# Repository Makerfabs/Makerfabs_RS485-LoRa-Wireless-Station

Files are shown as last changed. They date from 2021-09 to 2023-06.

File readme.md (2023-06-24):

# Industrial-grade Soil Remote Monitor

```c++
/*
Version:		V2.0
Author:			Vincent
Create Date:	2023/3/1
Note:
		2023/3/1	V2.0: Use new sensor, change request code.
*/
```

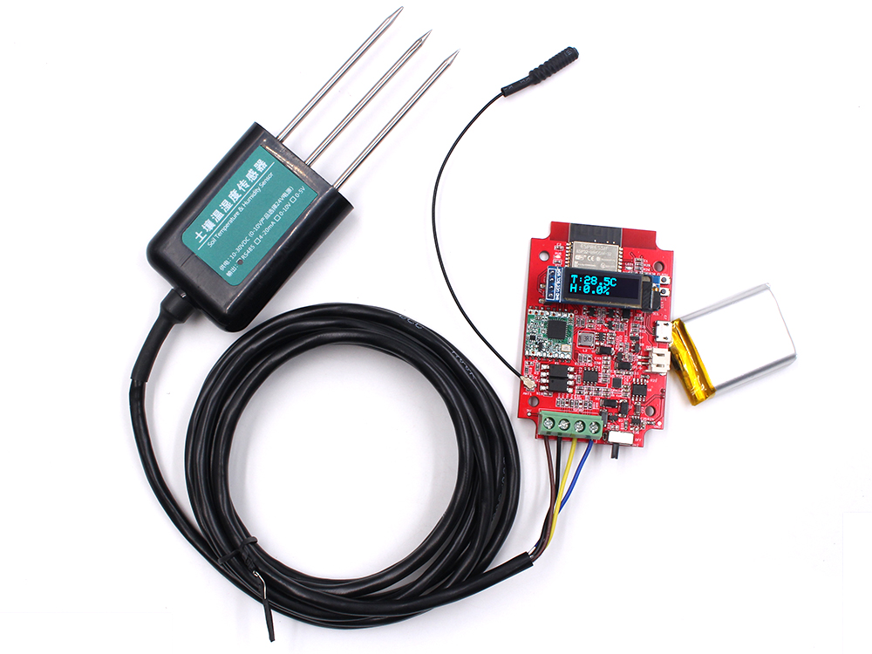
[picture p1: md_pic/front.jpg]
main


[toc]

# Makerfabs

[Makerfabs home page](https://www.makerfabs.com/)

[Makerfabs Wiki](https://wiki.makerfabs.com/)

# Industrial-grade Soil Remote Monitor

## Intruduce

Product Link ：[Industrial-grade Soil Remote Monitor(Humidity/ Temperature/ PH/ Nitrogen/ Phosphorus/ Potassium)](https://www.makerfabs.com/industrial-grade-soil-remote-monitor.html) 

Wiki Link : [RS485-LoRa Wireless Station](https://wiki.makerfabs.com/Industrial-grade_Soil_Remote_Monitor.html) 

With the development of agricultural modernization and the popularization of precision agriculture, the remote monitoring of soil parameters such as temperature, moisture, PH, and so on, becomes more important.

This Industry-grade soil remote monitor intends for these applications of agriculture, it is mainly composed of 2 parts:

**1. Remote monitor station with RS485:** developed by Makerfabs, it converts the RS485 signal, which is usually used in agricultural field applications, to wireless connections WIFI (if there is) or Lora, or Bluetooth.
**2. Industrial-grade Soil Sensor:** unlike some other maker-level soil sensors that only output analog voltage that reflects the soil status/changes but not the absolute value, this sensor measures the soil parameters such Temperature/Moisture/PH/Nitrogen/ Phosphorus/Potassium.., with calculated true output, so users can get to know the real soil parameters.

## Feature

- ESP32 WROOM module onboard with the WiFi and Bluetooth
- Arduino Compatible: You can play it with Arduino IDE
- Onboard LoRa module (433Mhz or 868Mhz or 915Mhz)
- 0.91inch I2C OLED display
- Sensor part is waterproof, completely sealed
- Measuring range: -40℃~80℃，0~100% moisture
- Measuring accuracy: ±0.5℃，±3% moisture
- Communication distance: Lora: 2km or more; WIFI: No such parameter
- Power by Micro USB, battery, or DC 5V
- 1000mAh battery, charger IC onboard

# Code

## Compiler Options

**If you have any questions，such as how to install the development board, how to download the code, how to install the library. Please refer to :[Makerfabs_FAQ](https://github.com/Makerfabs/Makerfabs_FAQ)**

- Install board : ESP32 .
- Install library : Adafruit GFX library (V1.10.11) , Adafruit SSD1306 library (V2.4.6) and RadioLib library 4.0.6.
- Upload codes, select "ESP32 Dev Module"

## Sensor User Manual

Cable definition:

- Grey cable: DC 5V power supply +
- Black line: Power ground (GND)
- Yellow and green wires: RS485-A;
- Brown cable: RS485-B.

The sensor uses Modbus RTU.

Request Command：**01 04 00 00 00 07 B1 C8**

- 0x01 Sensor address; 
- 0x04 function code; 
- 0x00 0x00 read register start position; 
- 0x00 0x07 Number of registers read; 
- 0xB1 0xC8  Check

Receive Data：**01 04 0E 01 D7 01 07 00 00 00 46 00 0F 00 14 00 32 CC 93**

- 0x01 Sensor address;
- 0x04 function code;
- 0x0E data length;
- 0x01 0xD7 Soil moisture data 01 D7 (hexadecimal) is 47.1%
- 0x01 0x07 Soil Temperature Data 01 07 (hexadecimal) is 26.3 ° C
- 0x00 0x00 blank
- 0x00 0x46 PH data 00 46 (hexadecimal) is 7.0
- 0x00 0x0F Soil Nitrogen data 00 0F (hexadecimal) is 15mg/kg
- 0x00 0x14 Soil Phosphorus data 00 14 (hexadecimal) is 20mg/kg
- 0x00 0x32 Soil potassium data 00 32 (hexadecimal) is 50mg/kg
- 0xCC 0x93 check

| Parameter | Address | Range | Sampling Value | Action |
| --- | --- | --- | --- | --- |
| Humidity | 0000H | 0~100% | /10 | Only Read |
| Temperature | 0001H | -40~80℃ | /10 | Only Read |
| PH | 0003H | 4~9 | /10 | Only Read |
| Nitrogen | 0004H | 0~1999mg/kg | /1 | Only Read |
| Phosphorus  | 0005H | 0~1999mg/kg | /1 | Only Read |
| Potassium | 0006H | 0~1999mg/kg | /1 | Only Read |

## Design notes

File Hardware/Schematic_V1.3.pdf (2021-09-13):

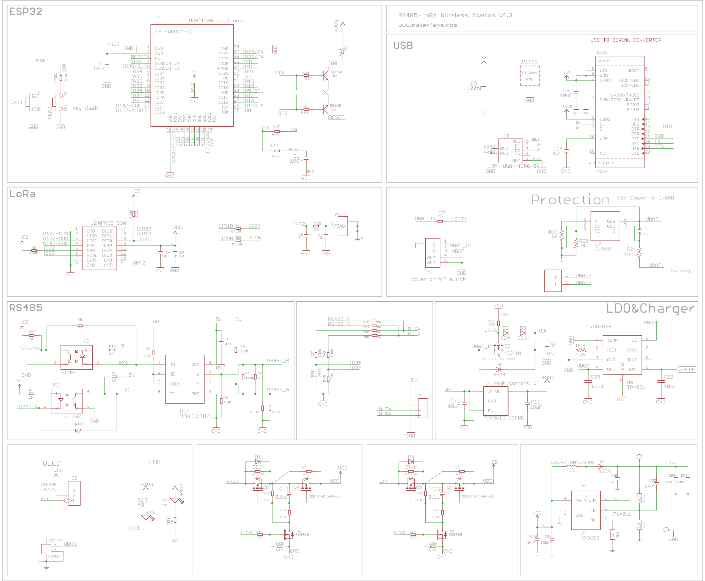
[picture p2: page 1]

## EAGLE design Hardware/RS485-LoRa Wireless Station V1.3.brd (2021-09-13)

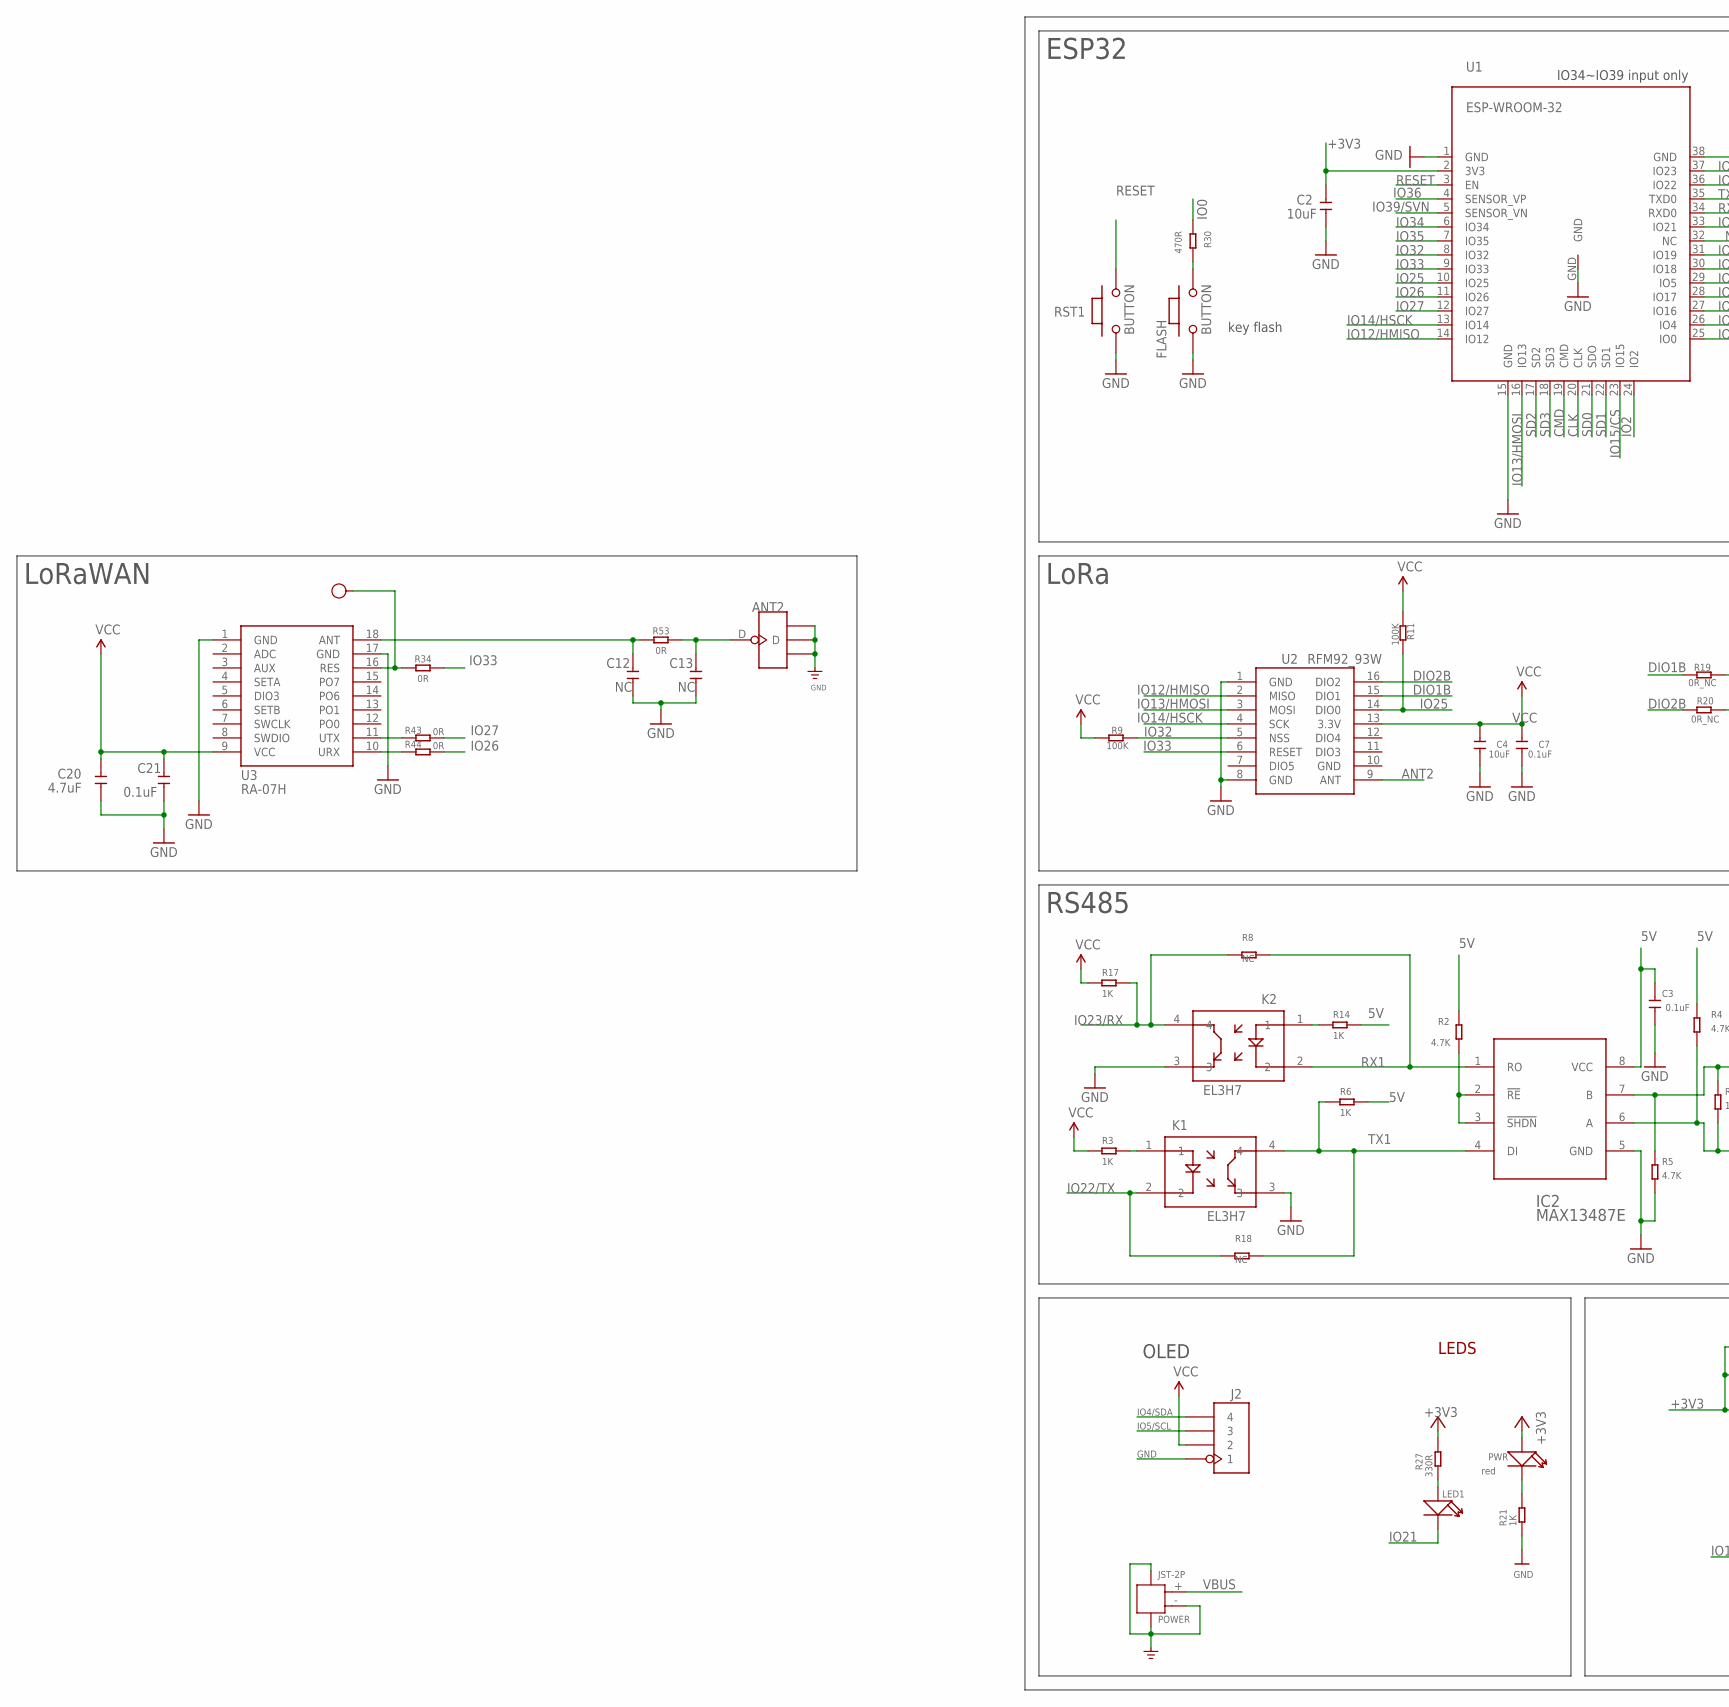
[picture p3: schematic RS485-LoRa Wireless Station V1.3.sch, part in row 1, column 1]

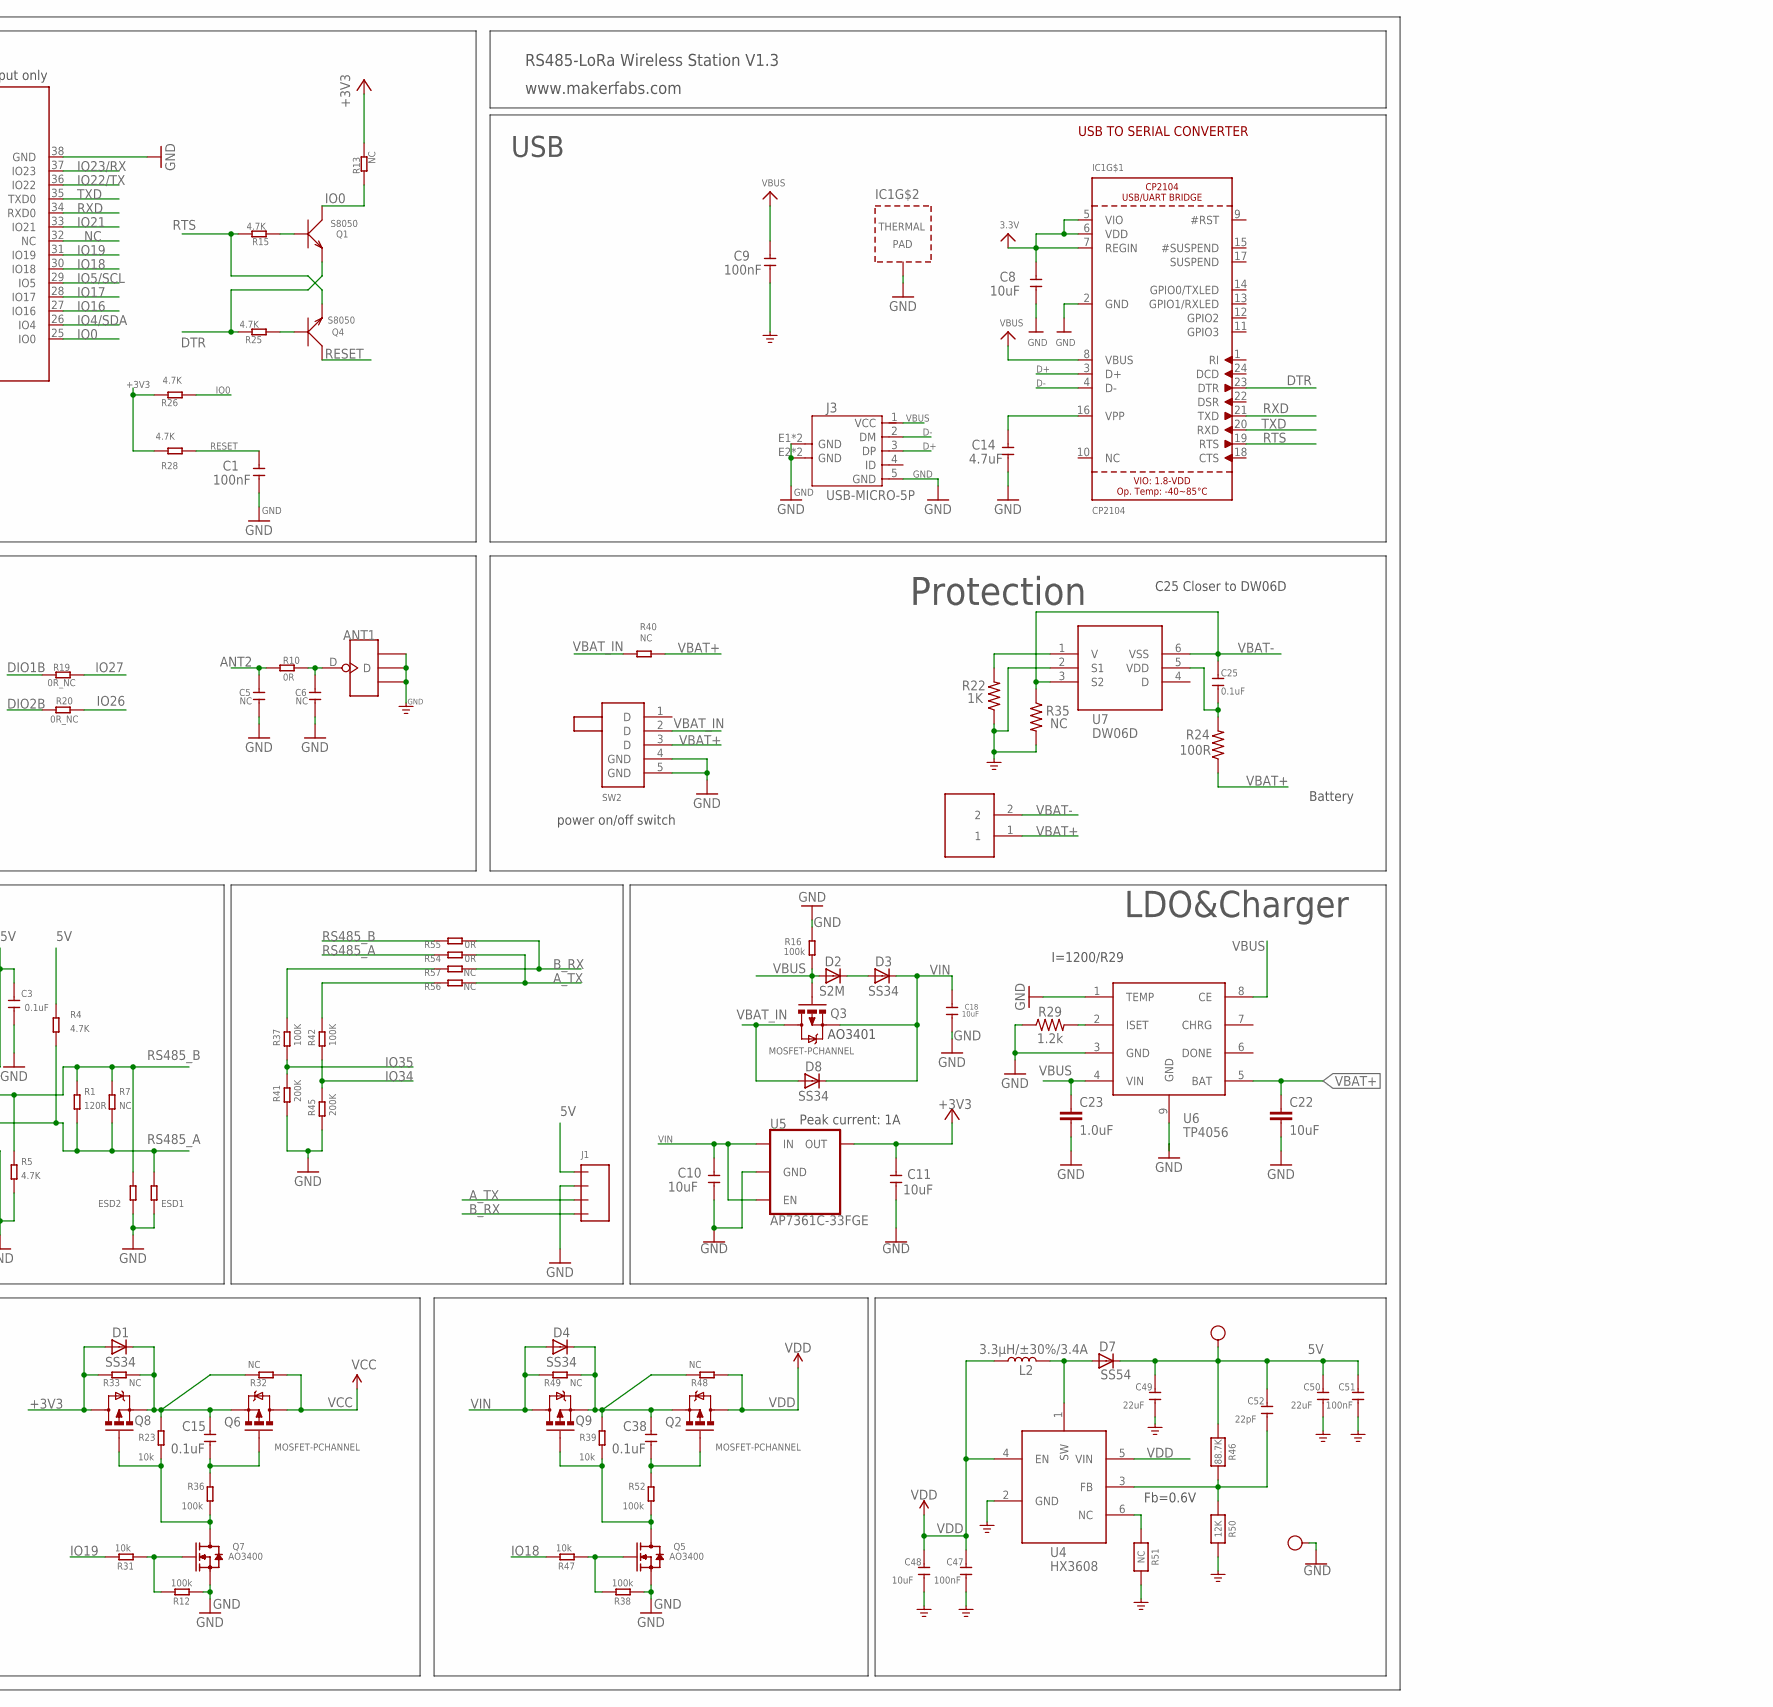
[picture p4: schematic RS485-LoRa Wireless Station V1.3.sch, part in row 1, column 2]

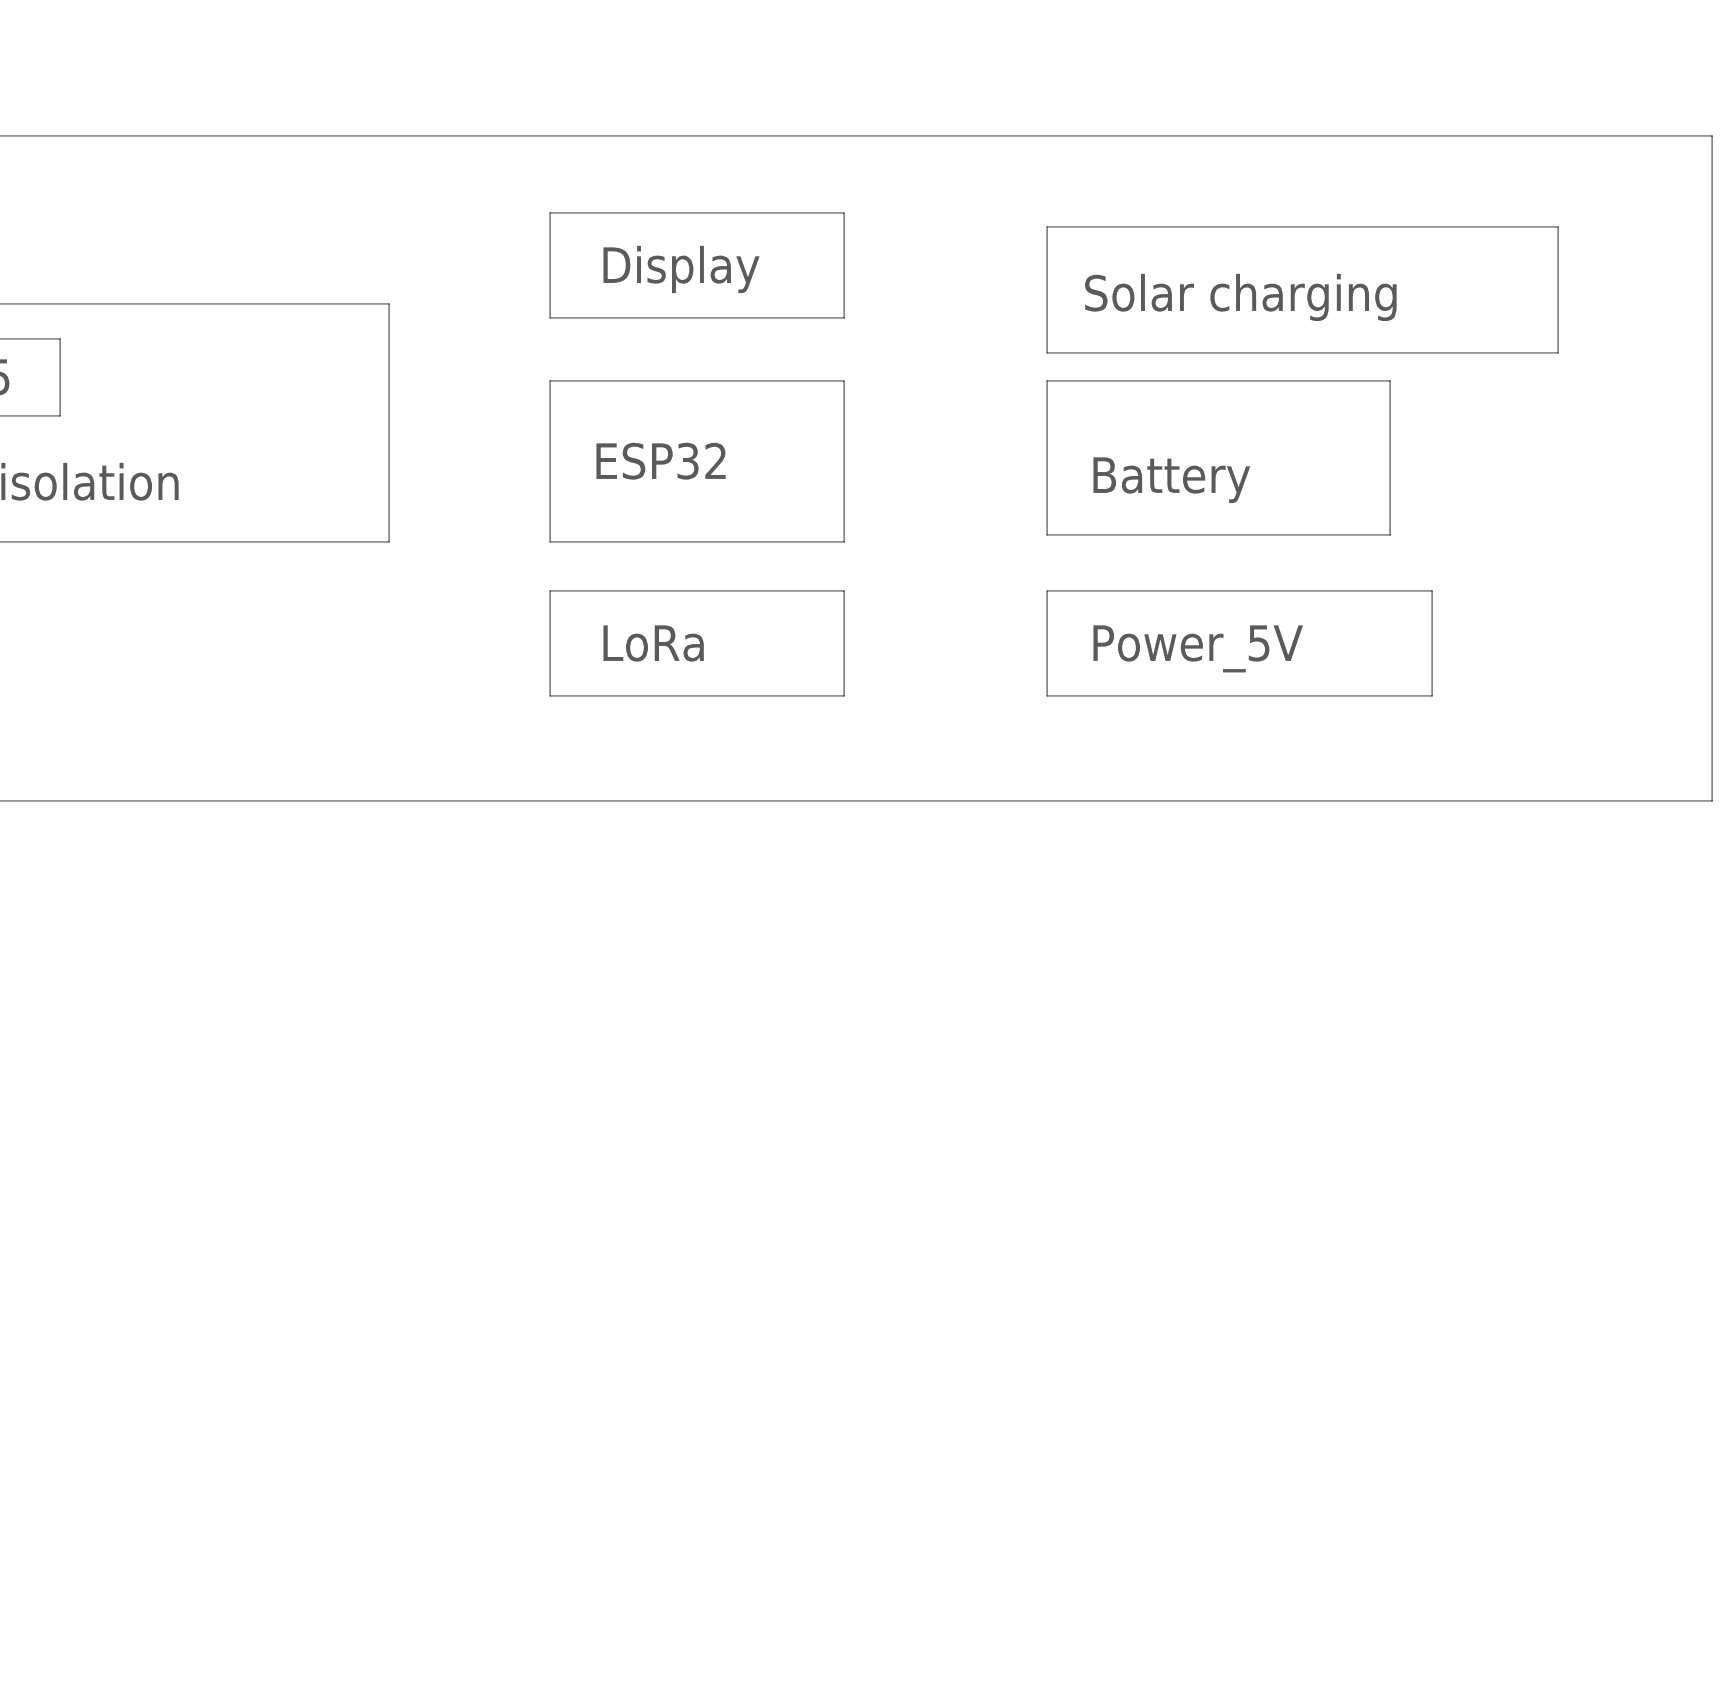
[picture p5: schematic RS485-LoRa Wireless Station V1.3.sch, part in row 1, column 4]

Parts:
5V: TEST-POINT'4545'; TP-D45MIL
ANT1, ANT2: ANTENNA-U-FL; 4P-U-FL
C1, C9, C47, C51: 100nF; C0603
C2, C4, C8, C10, C11, C18, C48: 10uF; C0603
C3, C7, C15, C21, C25, C38: 0.1uF; C0603
C5, C6: NC; DISCRETE_C0603
C12, C13: NC; C0603
C14, C20: 4.7uF; C0603
C22: 10uF; 1206
C23: 1.0uF; 0603
C49, C50: 22uF; C0603
C52: 22pF; C0603
D1, D3, D4, D8: SS34; DO-214AC
D2: S2M; DO-214AC
D7: SS54; DO-214AC
ESD1, ESD2: R-0603; R0603
FLASH: BUTTON; 157SW
GND: TEST-POINT'4545'; TP-D45MIL
IC1: CP2104; QFN24_4MM_SMSC
IC2: MAX13487E; DIP8_MAX13487
J1: J_4P_5.08; DIP4_5.08
J2: HEADER-1X4P; SMD4-2.54P
J3: USB-MICRO-5P; MICRO-USB-5P
J5: PH2.0-2P-90-DIP
K1, K2: EL3H7; SOP-4_P1.27
L2: 3.3µH/±30%/3.4A; CR54
LED1: DISCRETE_LED0603; DISCRETE_LED-0603
POWER: JST-2P; HW2-SMD-2.0-90D
PWR: red; LED-0603
Q1, Q4: S8050; SOT23
Q2, Q3, Q6, Q8, Q9: MOSFET-PCHANNEL; SOT23-3
Q5, Q7: AO3400; SOT23@1
R1: 120R; R0603
R2, R4, R5, R15, R25, R26, R28: 4.7K; R0603
R3, R6, R14, R17, R21: 1K; R0603
R7, R8, R13, R18, R32, R33, R40, R48, R49, R56, R57: NC; R0603
R9, R11, R37, R42: 100K; R0603
R10: 0R; DISCRETE_R0603
R12, R16, R36, R38, R52: 100k; R0603
R19, R20: 0R_NC; R0603
R22: 1K; 0603
R23, R31, R39, R47: 10k; R0603
R24: 100R; 0603
R27: 330R; R0603
R29: 1.2k; 0603
R30: 470R; R0603
R34, R43, R44, R53, R54, R55: 0R; R0603
R35: NC; 0603
R41, R45: 200K; R0603
R46: 88.7K; 0603-NO
R50: 12K; 0603-NO
R51: NC; 0603-NO
RES: TEST-POINT'4545'; TP-D45MIL; PARTNO DNP
RST1: BUTTON; 157SW
SW2: SWITCH; DIP5-8.6*4.5MM
U1: ESP-WROOM-32
U2: RFM92_93W
U3: RA-07H; SMD18-127P-1600L1600W
U4: HX3608; SOT-23-6
U5: AP7361C-33FGE; 8-UDFN
U6: TP4056; SOP8-1.27P
U7: DW06D; SOT-23-6

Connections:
5V: 5V.T, C3.2, C49.1, C50.1, C51.1, C52.1, D7.C, IC2.8 (VCC), J1.P$1 (1), R2.2, R4.2, R6.1, R14.1, R46.1
+3V3: C2.2, C8.2, C11.2, D1.A, IC1.5 (VIO), IC1.6 (VDD), IC1.7 (REGIN), PWR.+, Q8.3 (D), R13.1, R26.1, R27.2, R28.1, R33.2, U1.2 (3V3), U5.1 (OUT)
ANT2: C5.2, R10.1, U2.9 (ANT)
A_TX: J1.P$3 (3), R54.1, R56.1
B_RX: J1.P$4 (4), R55.1, R57.1
CLK: U1.20 (CLK)
CMD: U1.19 (CMD)
D+: IC1.3 (D+), J3.3 (DP)
D-: IC1.4 (D-), J3.2 (DM)
DIO1B: R19.2, U2.15 (DIO1)
DIO2B: R20.2, U2.16 (DIO2)
DTR: IC1.23 (DTR), Q1.2 (E), R25.1
GND: ANT1.GND1, ANT1.GND2, ANT1.GND3, ANT2.GND1, ANT2.GND2, ANT2.GND3, C1.1, C2.1, C3.1, C4.1, C5.1, C6.1, C7.1, C8.1, C9.1, C10.1, C11.1, C12.1, C13.1, C14.1, C18.1, C20.1, C21.1, C22.2, C23.2, C47.2, C48.2, C49.2, C50.2, C51.2, ESD1.1, ESD2.1, FLASH.1, GND.T, IC1.2 (GND), IC1.THERM (TP), IC2.5 (GND), J1.P$2 (2), J2.1, J3.5 (GND), J3.E1 (GND), J3.E2 (GND), J3.P1 (GND), J3.P2 (GND), K1.3, K2.3, POWER.3, POWER.4, POWER.- (2), Q5.2 (S), Q7.2 (S), R5.1, R12.1, R16.2, R21.1, R22.1, R29.1, R35.2, R38.1, R41.2, R45.2, R50.2, R51.2, RST1.1, SW2.4 (GND), SW2.5 (GND), U1.1 (GND), U1.15 (GND), U1.38 (GND), U1.GND, U2.1 (GND), U2.8 (GND), U2.10 (GND), U3.1 (GND), U3.17 (GND), U4.2 (GND), U5.4 (GND), U5.EP (GND), U6.1 (TEMP), U6.3 (GND), U6.9 (GND), U7.2 (S1)
IO0: Q1.3 (C), R13.2, R26.2, R30.2, U1.25 (IO0)
IO2: U1.24 (IO2)
IO4/SDA: J2.4, U1.26 (IO4)
IO5/SCL: J2.3, U1.29 (IO5)
IO12/HMISO: U1.14 (IO12), U2.2 (MISO)
IO13/HMOSI: U1.16 (IO13), U2.3 (MOSI)
IO14/HSCK: U1.13 (IO14), U2.4 (SCK)
IO15/CS: U1.23 (IO15)
IO16: U1.27 (IO16)
IO17: U1.28 (IO17)
IO18: R47.2, U1.30 (IO18)
IO19: R31.2, U1.31 (IO19)
IO21: LED1.-, U1.33 (IO21)
IO22/TX: K1.2, R18.2, U1.36 (IO22)
IO23/RX: K2.4, R8.2, R17.1, U1.37 (IO23)
IO25: R11.1, U1.10 (IO25), U2.14 (DIO0)
IO26: R20.1, R44.2, U1.11 (IO26)
IO27: R19.1, R43.2, U1.12 (IO27)
IO32: R9.1, U1.8 (IO32), U2.5 (NSS)
IO33: R34.2, U1.9 (IO33), U2.6 (RESET)
IO34: R42.2, R45.1, U1.6 (IO34)
IO35: R37.2, R41.1, U1.7 (IO35)
IO36: U1.4 (SENSOR_VP)
IO39/SVN: U1.5 (SENSOR_VN)
ISET: R29.2, U6.2 (ISET)
unnamed: K2.1, R14.2
unnamed: D2.C, D3.A
unnamed: K1.1, R3.1
unnamed: ANT1.D, C6.2, R10.2
unnamed: LED1.+, R27.1
unnamed: C14.2, IC1.16 (VPP)
unnamed: PWR.-, R21.2
unnamed: Q4.1 (B), R25.2
unnamed: Q1.1 (B), R15.2
unnamed: FLASH.2, R30.1
unnamed: C38.1, Q2.1 (G), R52.2
unnamed: Q5.1 (G), R38.2, R47.1
unnamed: C15.1, Q6.1 (G), R36.2
unnamed: Q7.1 (G), R12.2, R31.1
unnamed: C15.2, D1.C, Q6.2 (S), Q8.2 (S), R23.2, R32.2, R33.1
unnamed: C25.2, R24.2, U7.5 (VDD)
unnamed: R22.2, U7.1 (V)
unnamed: Q7.3 (D), Q8.1 (G), R23.1, R36.1
unnamed: R42.1, R56.2
unnamed: C38.2, D4.C, Q2.2 (S), Q9.2 (S), R39.2, R48.2, R49.1
unnamed: R37.1, R57.2
unnamed: R43.1, U3.11 (UTX)
unnamed: D7.A, L2.P$2 (2), U4.1 (SW)
unnamed: R44.1, U3.10 (URX)
unnamed: C52.2, R46.2, R50.1, U4.3 (FB)
unnamed: R51.1, U4.6 (NC)
unnamed: R34.1, RES.T, U3.16 (RES)
unnamed: C12.2, R53.1, U3.18 (ANT)
unnamed: ANT2.D, C13.2, R53.2
unnamed: Q5.3 (D), Q9.1 (G), R39.1, R52.1
unnamed: IC2.2 (!RE), IC2.3 (!SHDN), R2.1
NC: U1.32 (NC)
RESET: C1.2, Q4.3 (C), R28.2, RST1.2, U1.3 (EN)
RS485_A: ESD1.2, IC2.6 (A), R1.1, R4.1, R7.1, R54.2
RS485_B: ESD2.2, IC2.7 (B), R1.2, R5.2, R7.2, R55.2
RTS: IC1.19 (RTS), Q4.2 (E), R15.1
RX1: IC2.1 (RO), K2.2, R8.1
RXD: IC1.21 (TXD), U1.34 (RXD0)
SD0: U1.21 (SDO)
SD1: U1.22 (SD1)
SD2: U1.17 (SD2)
SD3: U1.18 (SD3)
TX1: IC2.4 (DI), K1.4, R6.2, R18.1
TXD: IC1.20 (RXD), U1.35 (TXD0)
VBAT+: C22.1, J5.1, R24.1, R40.2, SW2.3 (D), U6.5 (BAT)
VBAT-: C25.1, J5.2, R35.1, U7.3 (S2), U7.6 (VSS)
VBAT_IN: D8.A, Q3.3 (D), R40.1, SW2.2 (D)
VBUS: C9.2, C23.1, D2.A, IC1.8 (VBUS), J3.1 (VCC), POWER.+ (1), Q3.1 (G), R16.1, U6.4 (VIN), U6.8 (CE)
VCC: C4.2, C7.2, C20.2, C21.2, J2.2, Q6.3 (D), R3.2, R9.2, R11.2, R17.2, R32.1, U2.13 (3.3V), U3.9 (VCC)
VDD: C47.1, C48.1, L2.P$1 (1), Q2.3 (D), R48.1, U4.4 (EN), U4.5 (VIN)
VIN: C10.2, C18.2, D3.C, D4.A, D8.C, Q3.2 (S), Q9.3 (D), R49.2, U5.5 (EN), U5.8 (IN)

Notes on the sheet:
Peak current: 1A
LDO&Charger
AO3401
I=1200/R29
Battery
C25 Closer to DW06D
Protection
power on/off switch
OLED
Fb=0.6V
ESP32
LoRa
Power_5V
Solar charging
RS485
LEDS
IO34~IO39 input only
key flash
Photoelectric isolation
USB TO SERIAL CONVERTER
Display
USB
LoRaWAN
RS485-LoRa Wireless Station V1.3
www.makerfabs.com

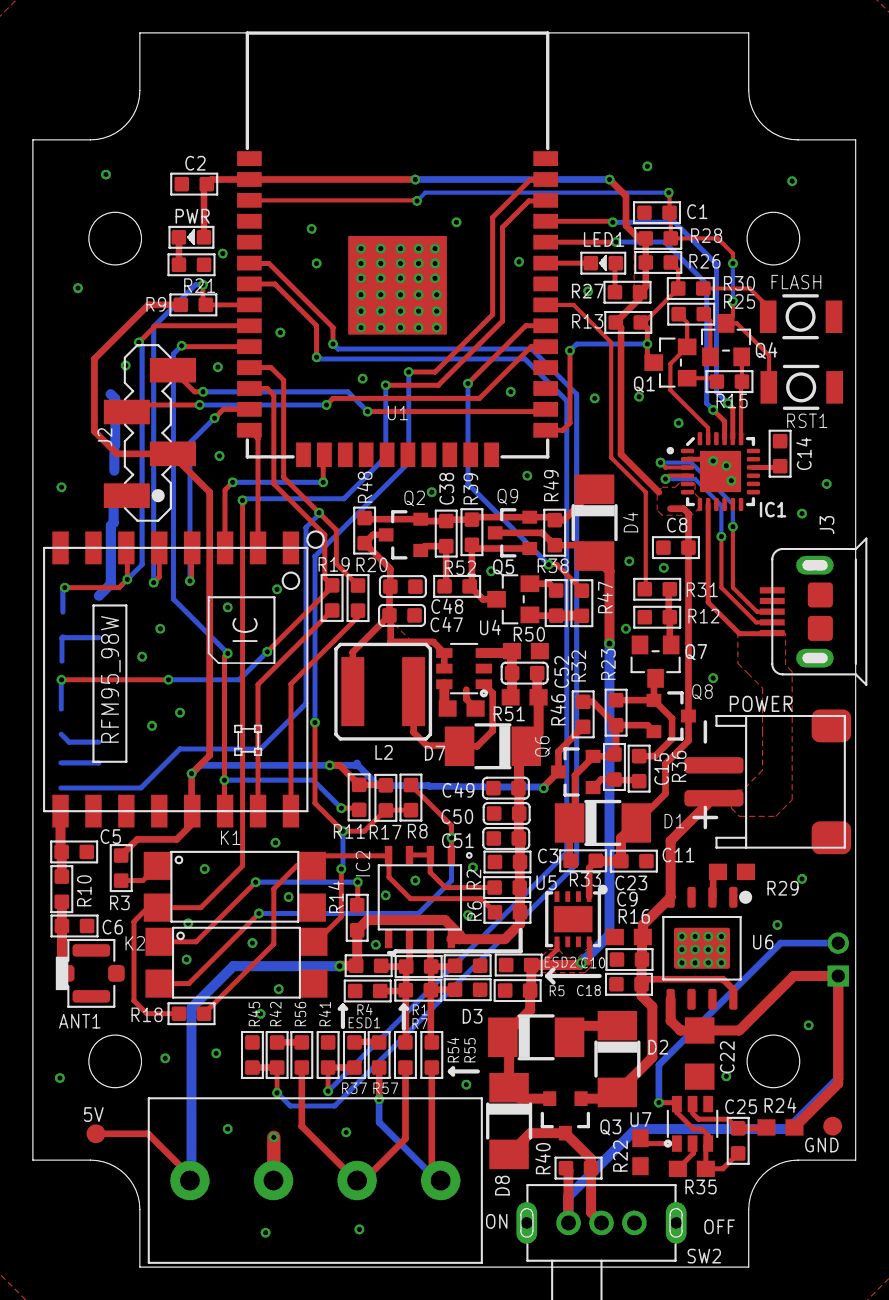
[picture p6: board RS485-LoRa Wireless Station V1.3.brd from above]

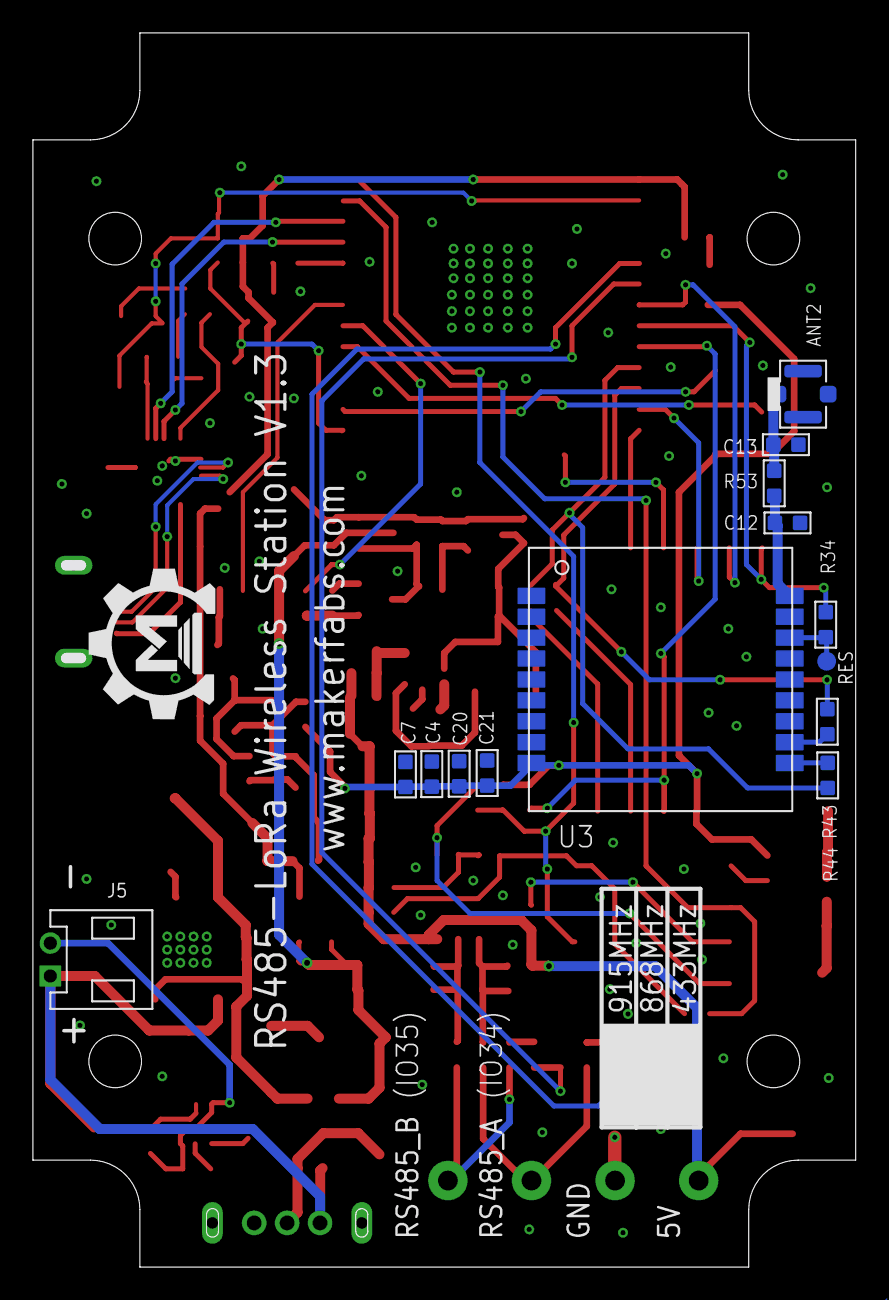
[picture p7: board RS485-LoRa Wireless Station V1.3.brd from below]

Board: 2 copper layers, 50.0 x 75.0 mm, 130 parts (15 on the bottom side), 76 nets.

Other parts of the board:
U$9: MAKERFABS_0.3

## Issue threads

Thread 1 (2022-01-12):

MySerial could contain more then 18 objects

littlejogi, 2022-01-12:
Sometimes the start of RS485-display-all.ino fails because MySerial could contain more then 18 (unused) objects

littlejogi, 2022-01-12:
Fix:
```
#include <RadioLib.h>
#include <SPI.h>
#include <Wire.h>
#include <Adafruit_GFX.h>
#include <Adafruit_SSD1306.h>
#include <HardwareSerial.h>

#define SCREEN_WIDTH 128 // OLED display width, in pixels
#define SCREEN_HEIGHT 32 // OLED display height, in pixels

#define OLED_RESET -1 // Reset pin # (or -1 if sharing Arduino reset pin)
Adafruit_SSD1306 display(SCREEN_WIDTH, SCREEN_HEIGHT, &Wire, OLED_RESET);

#define Display_power 19
#define RS485_power 18

//esp32
#define DIO0 25
#define DIO1 27

#define ESP32_SDA 4
#define ESP32_SCL 5

#define LORA_RST 33
#define LORA_CS 32

#define SPI_MOSI 13
#define SPI_MISO 12
#define SPI_SCK 14

#define FREQUENCY 434.0
#define BANDWIDTH 125.0
#define SPREADING_FACTOR 9
#define CODING_RATE 7
#define OUTPUT_POWER 10
#define PREAMBLE_LEN 8
#define GAIN 0

#define MYSerialRX 23
#define MYSerialTX 22

HardwareSerial MySerial(1);

unsigned char test_command[8] = {0X01,0X03,0X00,0X00,0X00,0X07,0X04,0X08};

unsigned char test_response[19] = {};

int moisture;
int tem;
int ph;
float moisture_value;
float tem_value;
float ph_value;
int P_value;
int N_value;
int K_value;
float P_float_value;
float N_float_value;
float K_float_value;

void setup() {
    // put your setup code here, to run once:
    Serial.begin(115200);

    MySerial.begin(4800, SERIAL_8N1, 23, 22);

    pinMode(Display_power,OUTPUT);
    pinMode(RS485_power,OUTPUT);
    delay(50);
    digitalWrite(Display_power, HIGH);
    digitalWrite(RS485_power, HIGH);
    delay(1000);

    Serial.println(" Test Begin!");

    Wire.begin(ESP32_SDA,ESP32_SCL);
    // SSD1306_SWITCHCAPVCC = generate display voltage from 3.3V internally
    if (!display.begin(SSD1306_SWITCHCAPVCC, 0x3C))
    { // Address 0x3C for 128x32
      Serial.println(F("SSD1306 allocation failed"));
      for (;;)
        ; // Don't proceed, loop forever
    }
    Serial.println("SSD1306 found");

    //logo_show();

    MySerial.write(test_command,8);
    delay(1000);
    MySerial.write(test_command,8);
    delay(1000);

}

void loop() {

    delay(1000);
    //********************GET Temperature, Moisture and PH*******************
    MySerial.write(test_command,8);
    int i = 0;
    while (MySerial.available() > 0 )
    {
        Serial.print("Read #"+String(i)+" == ");
        if (i<19)
        {
          test_response[i] = MySerial.read();
          Serial.println(String(test_response[i])+" (a)");
        }
        else
        {
          unsigned char tmp=MySerial.read();
          Serial.println(String(tmp)+ "(b)");
        }
        i++;
        yield();
    }
    for(int j=0;j<19;j++)
      {Serial.print((int)test_response[j]);
      Serial.print("  ");}
    Serial.print("\n");
    moisture = CaculateValue((int)test_response[3],(int)test_response[4]);
    moisture_value = moisture*0.1 ;
    tem = CaculateValue((int)test_response[5],(int)test_response[6]);
    tem_value = tem*0.1;
    ph = CaculateValue((int)test_response[9],(int)test_response[10]);
    ph_value = ph*0.1;

    Serial.println("M= "+String(moisture_value)+" %");
    Serial.println("T= "+String(tem_value)+" °C");
    Serial.println("P= "+String(ph_value)+" ");
    value_show(moisture_value, tem_value, ph_value);

    //****************GET Nitrogen, Phosphorus and Potassium

    delay(1000);

    N_value = CaculateValue((int)test_response[11],(int)test_response[12]);
    P_value = CaculateValue((int)test_response[13],(int)test_response[14]);
    K_value = CaculateValue((int)test_response[15],(int)test_response[16]);

    Serial.print("N= ");
    Serial.print(N_value);
    Serial.println(" mg/kg");
    Serial.print("P= ");
    Serial.print(P_value);
    Serial.println(" mg/kg");
    Serial.print("K= ");
    Serial.print(K_value);
    Serial.println(" mg/kg");

    NPK_Show(N_value, P_value, K_value);

}

void logo_show()
{
  display.clearDisplay();

  display.setTextColor(SSD1306_WHITE);
  display.setTextSize(2); // Draw 2X-scale text
  display.setCursor(10, 0);
  display.println(F("Makerfabs"));
  display.setTextSize(1);
  display.setCursor(10, 16);
  display.println(F("RS485-LoRa"));
  display.display(); // Show initial text
  delay(100);

  // Scroll in various directions, pausing in-between:
  display.startscrollright(0x00, 0x01);
  delay(4000);
  display.startscrolldiagright(0x00, 0x07);
  delay(2000);
  display.startscrolldiagleft(0x00, 0x07);
  delay(2000);
  display.stopscroll();
}

int CaculateValue(int x, int y)
{
  int t = 0;
  t = x*256;
  t = t+y;
  return t;
}

void value_show(float h, float t, float ph_f)
{
  display.clearDisplay();

  display.setTextColor(SSD1306_WHITE);
  display.setTextSize(1); // Draw 2X-scale text
  display.setCursor(2, 0);
  display.print(F("T:"));
  display.print(t,1);
  display.print(F("C"));

  display.setCursor(66, 0);
  display.print(F("H:"));
  display.print(h,1);
  display.print(F("%"));

  display.setCursor(2, 16);
  display.print(F("PH:"));
  display.print(ph_f,1);

  display.display(); // Show initial text
  delay(3000);
}

void NPK_Show(int N, int P, int K)
{
  display.clearDisplay();

  display.setTextColor(SSD1306_WHITE);
  display.setTextSize(1); // Draw 2X-scale text
  display.setCursor(2, 0);
  display.print(F("N:"));
  display.print(N);
  //display.print(F("C"));

  display.setCursor(66, 0);
  display.print(F("P:"));
  display.print(P);
  //display.print(F("%"));

  display.setCursor(2, 16);
  display.print(F("K:"));
  display.print(K);
  display.print(F(" mg/kg"));

  display.display(); // Show initial text
  delay(3000);
}

/*
 * unsigned char testcode[236] = {0XFD,0XFD,0X30,0X3,...
 * Serial.write(testcode,236);
 *
 */
```

atjamil, 2022-02-16:
Thank you

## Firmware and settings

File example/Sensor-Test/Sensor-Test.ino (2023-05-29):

// Vincent Fix 2023/5/24
// Need Choice Sensor Type !

#define SENSOR_5_PIN
// #define SENSOR_3_PIN

#include <HardwareSerial.h>

#include "pin_config.h"

HardwareSerial MySerial(1);

unsigned char resp[80] = {0};

int humidity = 0;
int tem = 0;
int ph = 0;
float humidity_value = 0.0;
float tem_value = 0.0;
float ph_value = 0.0;
int P_value = 0;
int N_value = 0;
int K_value = 0;

void setup()
{
    // put your setup code here, to run once:
    Serial.begin(4800);
    MySerial.begin(4800, SERIAL_8N1, 23, 22);

    pinMode(Display_power, OUTPUT);
    pinMode(RS485_power, OUTPUT);
    delay(50);
    digitalWrite(Display_power, HIGH);
    digitalWrite(RS485_power, HIGH);
    delay(1000);

    Serial.println(" Test Begin!");
}

void loop()
{
    Serial.println("Send loop");

#ifdef SENSOR_5_PIN
    sensor_read_5pin();
    value_log();
    delay(3000);
#endif

#ifdef SENSOR_3_PIN
    sensor_read_3pin();
    value_log();
    delay(3000);
#endif
}

void sensor_read_3pin()
{
    unsigned char ask_cmd[8] = {0X01, 0X03, 0X00, 0X00, 0X00, 0X02, 0XC4, 0X0B};
    MySerial.write(ask_cmd, 8);
    int i = 0;

    while (MySerial.available() > 0 && i < 80)
    {
        resp[i] = MySerial.read();
        i++;

        yield();
    }
    Serial.print("Answer Length:");
    Serial.println(i);

    for (int j = 0; j < 19; j++)
    {
        Serial.print((int)resp[j]);
        Serial.print("  ");
    }
    Serial.print("\n");

    humidity = CaculateValue((int)resp[3], (int)resp[4]);
    humidity_value = humidity * 0.1;
    tem = CaculateValue((int)resp[5], (int)resp[6]);
    tem_value = tem * 0.1;
}

void sensor_read_5pin()
{
    unsigned char ask_cmd[8] = {0X01, 0X04, 0X00, 0X00, 0X00, 0X07, 0XB1, 0XC8};
    MySerial.write(ask_cmd, 8);
    int i = 0;

    while (MySerial.available() > 0 && i < 80)
    {
        resp[i] = MySerial.read();
        i++;

        yield();
    }

    Serial.print("Answer Length:");
    Serial.println(i);

    char temp[20];
    for (int j = 0; j < 19; j++)
    {
        sprintf(temp, "%02X ", (int)resp[j]);
        Serial.printf(temp);
    }

    Serial.print("\n");

    humidity = CaculateValue((int)resp[3], (int)resp[4]);
    humidity_value = humidity * 0.1;
    tem = CaculateValue((int)resp[5], (int)resp[6]);
    tem_value = tem * 0.1;
    ph = CaculateValue((int)resp[9], (int)resp[10]);
    ph_value = ph * 0.1;
    N_value = CaculateValue((int)resp[11], (int)resp[12]);
    P_value = CaculateValue((int)resp[13], (int)resp[14]);
    K_value = CaculateValue((int)resp[15], (int)resp[16]);
}

int CaculateValue(int x, int y)
{
    int t = 0;
    t = x * 256;
    t = t + y;
    return t;
}

void value_log()
{
    Serial.print("humidity:");
    Serial.println(humidity);
    Serial.print("humidity_value:");
    Serial.println(humidity_value);
    Serial.print("tem_value:");
    Serial.println(tem_value);

#ifdef SENSOR_5_PIN
    Serial.print("ph_value:");
    Serial.println(ph_value);

    Serial.print("N= ");
    Serial.print(N_value);
    Serial.println(" mg/kg");
    Serial.print("P= ");
    Serial.print(P_value);
    Serial.println(" mg/kg");
    Serial.print("K= ");
    Serial.print(K_value);
    Serial.println(" mg/kg");

#endif
}

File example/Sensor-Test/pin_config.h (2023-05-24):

#define SCREEN_WIDTH 128 // OLED display width, in pixels
#define SCREEN_HEIGHT 32 // OLED display height, in pixels

#define OLED_RESET -1 // Reset pin # (or -1 if sharing Arduino reset pin)

#define Display_power 19
#define RS485_power 18

// esp32
#define DIO0 25
#define DIO1 27

#define ESP32_SDA 4
#define ESP32_SCL 5

#define LORA_RST 33
#define LORA_CS 32

#define SPI_MOSI 13
#define SPI_MISO 12
#define SPI_SCK 14

#define FREQUENCY 434.0
#define BANDWIDTH 125.0
#define SPREADING_FACTOR 9
#define CODING_RATE 7
#define OUTPUT_POWER 10
#define PREAMBLE_LEN 8
#define GAIN 0

#define MYSerialRX 23
#define MYSerialTX 22

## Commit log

2021-09-13 Create hardware and demo code
    [RS485-LoRa Wireless Station V1.3.brd, RS485-LoRa Wireless Station V1.3.sch]
2023-03-01 New sensor update
2023-05-24 Compatible with two sensors.
2023-05-29 Add sensor test demo

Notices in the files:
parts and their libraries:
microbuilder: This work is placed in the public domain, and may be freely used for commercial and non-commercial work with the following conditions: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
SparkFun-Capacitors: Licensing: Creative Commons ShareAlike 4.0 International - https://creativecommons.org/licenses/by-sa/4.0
